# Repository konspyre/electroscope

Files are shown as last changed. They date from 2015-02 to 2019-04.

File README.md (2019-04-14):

# Toy Electroscope

Elsewhere: Check out the [through-hole version](https://github.com/konspyre/electroscope-through) of this electroscope

This is an Electroscope done up using a design from Alan "vk2zay" Yates in his [Making Electrets](http://www.youtube.com/watch?v=1DR-tTU8uIM) video.

Updated Toy Electroscope

### Postings

[Updated electroscope](http://open.konspyre.org/blog/2015-02-10-electroscope-update/)

[Initial release](http://open.konspyre.org/blog/2014/05/30/electroscope/)

### Direct fabrication

Latest/updated (use this one): [Updated electroscope (OSHPark shared project)](https://oshpark.com/shared_projects/x89XVFQf)

Older: [Old electroscope (OSHPark shared project)](https://www.oshpark.com/shared_projects/KFA2jmSs)

### Bill of Materials

This BOM specifies the amount needed for _one_ board.

| Quantity | Description | Digikey Part Number | Board Placement |
| --- | --- | --- | --- |
| 3 | 2N3906 | [MMBT3906FSCT-ND](http://www.digikey.com/product-detail/en/MMBT3906/MMBT3906FSCT-ND/458972) | Right (label: 2N3906) |
| 3 	 | 2N3904	 | [MMBT3904FSCT-ND](http://www.digikey.com/product-detail/en/MMBT3904/MMBT3904FSCT-ND/458971) | Left (label: 2N3904) |
| 2 | 100 ohm resistor (0603 imperial) | [1276-5038-1-ND](http://www.digikey.com/product-detail/en/RC1608J101CS/1276-5038-1-ND/) | Bottom (label: 100 ohm) |
| 2 | 100k ohm resistor (0603 imperial) | [1276-5110-1-ND](http://www.digikey.com/product-detail/en/RC1608J104CS/1276-5110-1-ND) | Middle (label: 100k ohm) |
| 2	 | 1M ohm resistor (0603 imperial) | [311-1.00MHRCT-ND](http://www.digikey.com/product-detail/en/RC0603FR-071ML/311-1.00MHRCT-ND/) | Top (label: 1M ohm) |
| 1 | 9v female PCB mount snap | [BSPCF](http://www.digikey.com/product-search/en?vendor=0&keywords=BSPCF) | 9V+ terminal (verify before soldering by attaching to a 9V battery -- reworking afterwards is difficult without specialized tools/materials) |
| 1 | 9v male PCB mount snap | [BSPCM](http://www.digikey.com/product-search/en?vendor=0&keywords=BSPCM) |  9V- terminal (verify before soldering by attaching to a 9V battery -- reworking afterwards is difficult without specialized tools/materials) |

#### LEDs

_Pick either the 3mm LEDs or surface mount 0805s_

| Quantity | Description | Digikey Part Number | Board Placement |
| --- | --- | --- | --- |
| 2 | 3mm LEDs | (Red: [160-1704-ND](http://www.digikey.com/product-search/en?vendor=0&keywords=160-1704-ND) / Green: [160-1958-ND](http://www.digikey.com/product-search/en?vendor=0&keywords=160-1958-ND) | Bottom (verify orientation before soldering!) |
| 2 | 0805 imperial LEDs | (Orange: [350-2040-1-ND](http://www.digikey.com/product-search/en?vendor=0&keywords=350-2040-1-ND) / Yellow: [350-2041-1-ND](http://www.digikey.com/product-search/en?vendor=0&keywords=350-2041-1-ND) | Bottom (verify orientation as with the 3mm LEDs) |

#### Antenna

There is no part for this, so you'll have to make your own. A simple loop soldered together usually
works well (the twisted termination used in the [previous photos](https://open.konspyre.org/assets/images/electroscope/top-old-ver-kapton.png) is just a fancy flourish).

#### Optional

Shielding: I experimented with a three-layered combination of kapton/polymide tape (to cover the BJTs), copper tape (edge to edge, touching the exposed ground edges), and then another layer of kapton/polymide to keep the copper looking nicely unscuffed by oils (from fingers).

### License

[CC0 1.0 Universal](https://creativecommons.org/publicdomain/zero/1.0)

Original design/schematic by [Alan "vk2zay" Yates](http://twitter.com/vk2zay)

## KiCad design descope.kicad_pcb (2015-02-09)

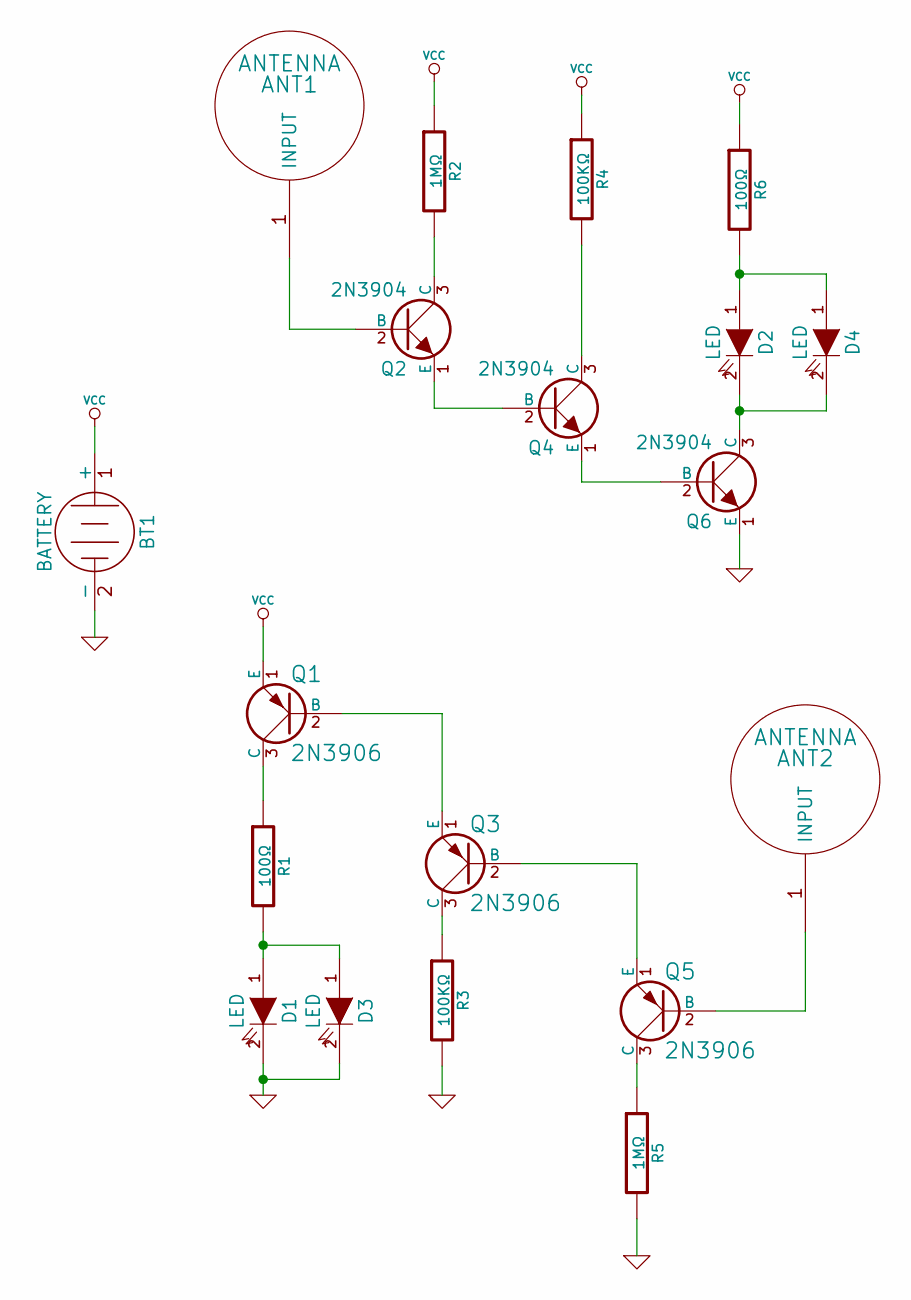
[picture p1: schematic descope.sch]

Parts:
ANT1, ANT2: ANTENNA
BT1: BATTERY
D1, D2, D3, D4: LED
Q1, Q3, Q5: 2N3906
Q2, Q4, Q6: 2N3904
R1, R6: 100Ω
R2, R5: 1MΩ
R3, R4: 100KΩ

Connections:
GND: BT1.2 (-), D1.2 (K), D3.2 (K), Q6.1 (E), R3.2, R5.2
unnamed: ANT1.1, Q2.2 (B)
unnamed: Q1.2 (B), Q3.1 (E)
unnamed: Q4.3 (C), R4.2
unnamed: Q4.1 (E), Q6.2 (B)
unnamed: Q2.1 (E), Q4.2 (B)
unnamed: Q2.3 (C), R2.2
unnamed: D1.1 (A), D3.1 (A), R1.2
unnamed: D2.2 (K), D4.2 (K), Q6.3 (C)
unnamed: D2.1 (A), D4.1 (A), R6.2
unnamed: ANT2.1, Q5.2 (B)
unnamed: Q5.3 (C), R5.1
unnamed: Q3.3 (C), R3.1
unnamed: Q1.3 (C), R1.1
unnamed: Q3.2 (B), Q5.1 (E)
VCC: BT1.1 (+), Q1.1 (E), R2.1, R4.1, R6.1

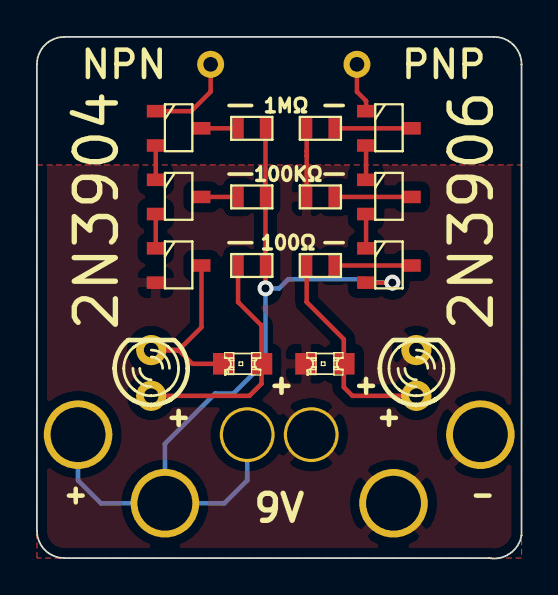
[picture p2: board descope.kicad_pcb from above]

Board: 2 copper layers, 26.9 x 29.0 mm, 19 parts (0 on the bottom side), 16 nets.

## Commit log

2014-05-30 Initial commit
    This is based off of commit 10acfe2 in the previous repository.
    [descope-B_Cu.gbl, descope-B_Mask.gbs, descope-B_SilkS.gbo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]
2014-05-30 Add README with BOM
2014-06-04 Add notes to 9v male part
2015-02-09 Add fabbed/generated gerbers
    [descope-B_Cu.gbl, descope-B_Mask.gbs, descope-B_SilkS.gbo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]
2015-02-09 Updated electroscope with pulled back copper pour
    [descope.kicad_pcb]
2019-04-14 README: Add a link to the through-hole version
